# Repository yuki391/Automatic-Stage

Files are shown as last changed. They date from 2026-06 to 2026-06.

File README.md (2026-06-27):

# 自動溶着ステージ

超音波溶着機を動かすための自動溶着ステージを制作したので、共有します。

## ファイルの説明
* **公開版.step**
  CADデータです。
* **自動ステージ用部品.xlsx**
  購入部品と3Dプリンターで製作した部品の一覧です。
* **使い方.pptx**
  私の環境で動かすときのマニュアル資料です。参考までに。
* **回路図.pptx**
  どのような配線をしたのかを記載しています。
* **その他 (.py, .json)**
  プログラムファイル群です。設定ファイル（.json）含め、すべて同じディレクトリで使用してください。
  ※ `foot_button.py`は溶着機をフットペダルでオンオフできるようにするものです。単独で実行するものではなく、`main_app.py`に組み込まれて動作します。

## 免責事項
本プロジェクトは素人が作成したものであり、改善できる点や間違いが含まれている可能性があります。
本データ（プログラム、CAD、回路図等）を使用したことによって生じたいかなる損害、事故、トラブルについても、作者は一切の責任を負いかねます。ご自身の責任において、安全に十分配慮した上でご活用ください。

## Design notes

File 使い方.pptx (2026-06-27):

## 自動ステージの使い方 (How to use an automatic stage)

- 2025/11/27

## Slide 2

目次

・P3 全体の流れ (Overall Flow)
・P4 注意事項 (Precautions)
・P5 手動で溶着する方法 (How to Weld Manually)
・P7 溶着方法 (Welding Method)
・P17 Q＆A

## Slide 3

流れ (flow)

溶着したい形を作製しdxfファイルで読み込ませる
(Create the shape you want to weld and import it as a DXF file.)
↓
溶着点データを作製・修正
(Creating and correcting welding point data)
↓
溶着開始
(Start of welding)

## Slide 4

注意事項 (Precaution)

・何かあったら非常停止ボタンを押してください．押した場合は最初からpythonプログラムの起動からやり直してください
(If anything happens, press the emergency stop button. If pressed, please restart the Python program from the beginning.)
・溶着機の先端や溶着したところは熱い可能性があるので気を付けてください
(Be careful, as the tip of the welding machine and the welded areas may be hot.)
・途中で緊急停止やトラブルがあると、溶着機の先端が下についていることがあります。この状態でXY軸を動かさないでください。
Z軸高さというところがあるのでここのパルス指定を2000にするか、pythonプログラムを終了し、もう一度立ち上げてください
(If an emergency stop or issue occurs mid-operation, the welder tip may remain lowered. Do NOT move the X and Y axes in this state. > Please set the パルス value in the " Z軸高さ" field to 2000, or close the Python program and restart it.)

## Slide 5

０　溶着機の使い方 (How to use)

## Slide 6

0　溶着機の外し方 (Removal of the Welding Machine)

①ねじを外す (Remove the screws)

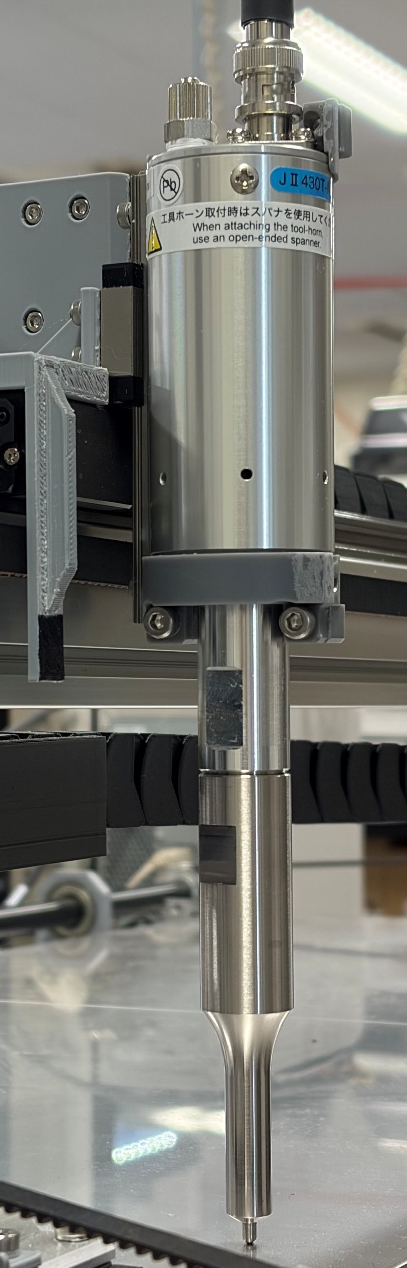
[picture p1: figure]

②ケーブルチェーンから線を外す
(Remove the cables from the cable chain)

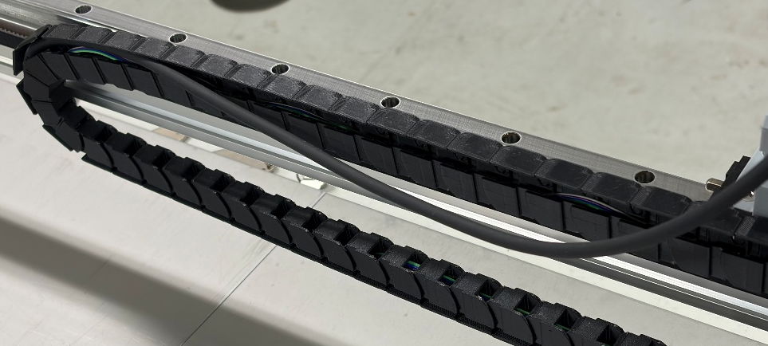
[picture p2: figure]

戻すときは逆の動作で。
溶着機本体を固定するときは向きに注意
(To reassemble, reverse the procedure. Note: Make sure the welding machine is facing the correct direction when securing it)

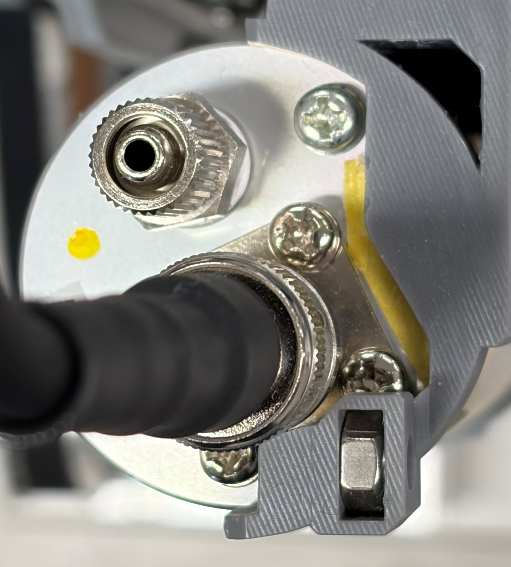
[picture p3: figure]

溶着機を上からみた図
(Top view of the welding machine)

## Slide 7

１　.dxfファイルを作製 (Create the DXF file)

SoildworksかFusion360でdxfファイルとして形をつくる
※注意※
複数の線が重なって構成されてるとエラーが出る
(Overlapping lines will cause an error)

〇

✕

線が重なってる

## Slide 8

２　配線を確認 (Check the wiring)

・コンセントに以下のものが差さっているか
(Check if the following are plugged into the outlet:)
①24V電源
②超音波溶着（本体後ろの電源をONに）
③Dynamixel
・パソコンと入出力ターミナルがつながってるか
(Check if the PC and the I/O terminal are connected)
・非常停止ボタンが押されたままになってないか
(Make sure the emergency stop button is not kept pressed down.)

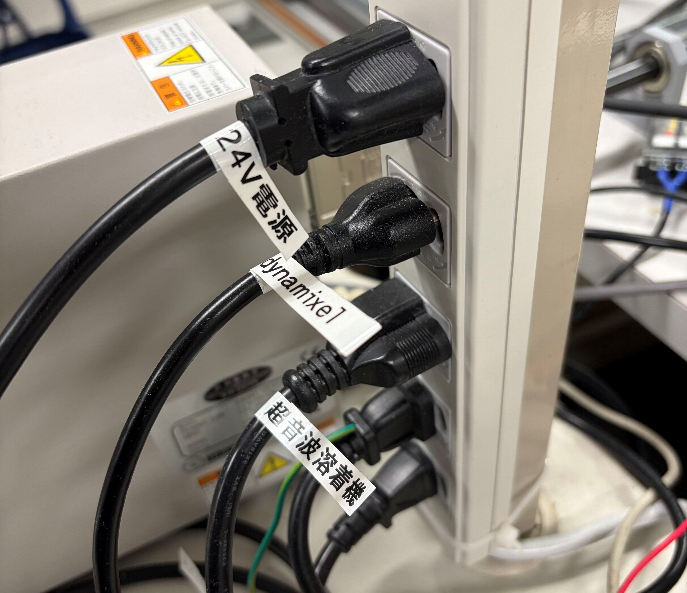
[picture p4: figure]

下二つのプラグはパソコンとモニター

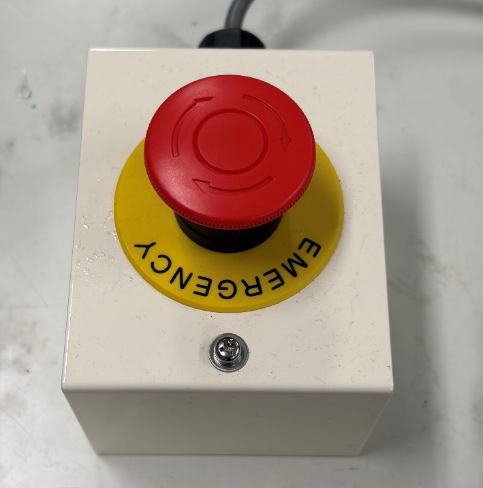
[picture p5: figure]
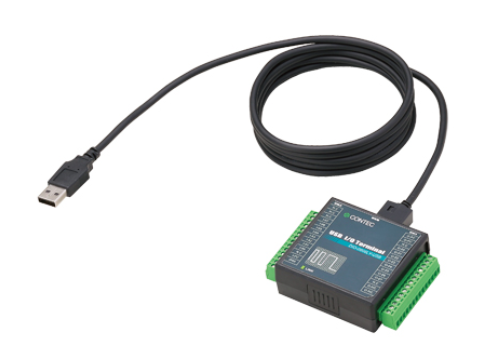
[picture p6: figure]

入出力ターミナル

押すとオン，赤いところを回すとオフ

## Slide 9

２　溶着用プログラムを起動 (Launch the welding program)

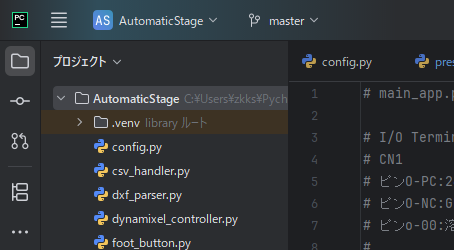
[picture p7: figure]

Pycharmを起動しAutomaticStageというプロジェクトを開く
(Launch PyCharm and open the "AutomaticStage" project)

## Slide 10

２　溶着用プログラムを起動 (Launch the welding program)

main_appを実行
(Run main_app)

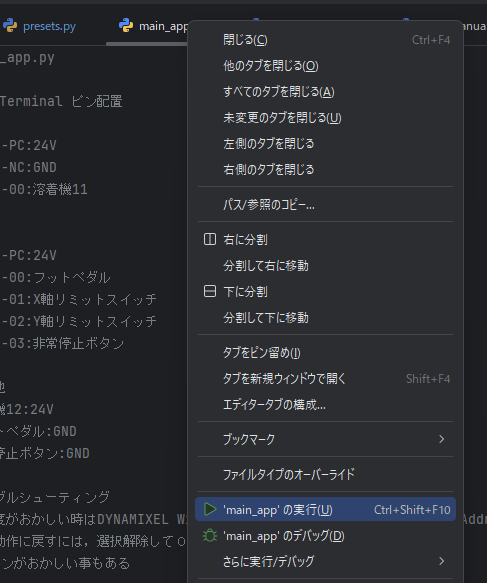
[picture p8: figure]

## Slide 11

３　手動操作画面

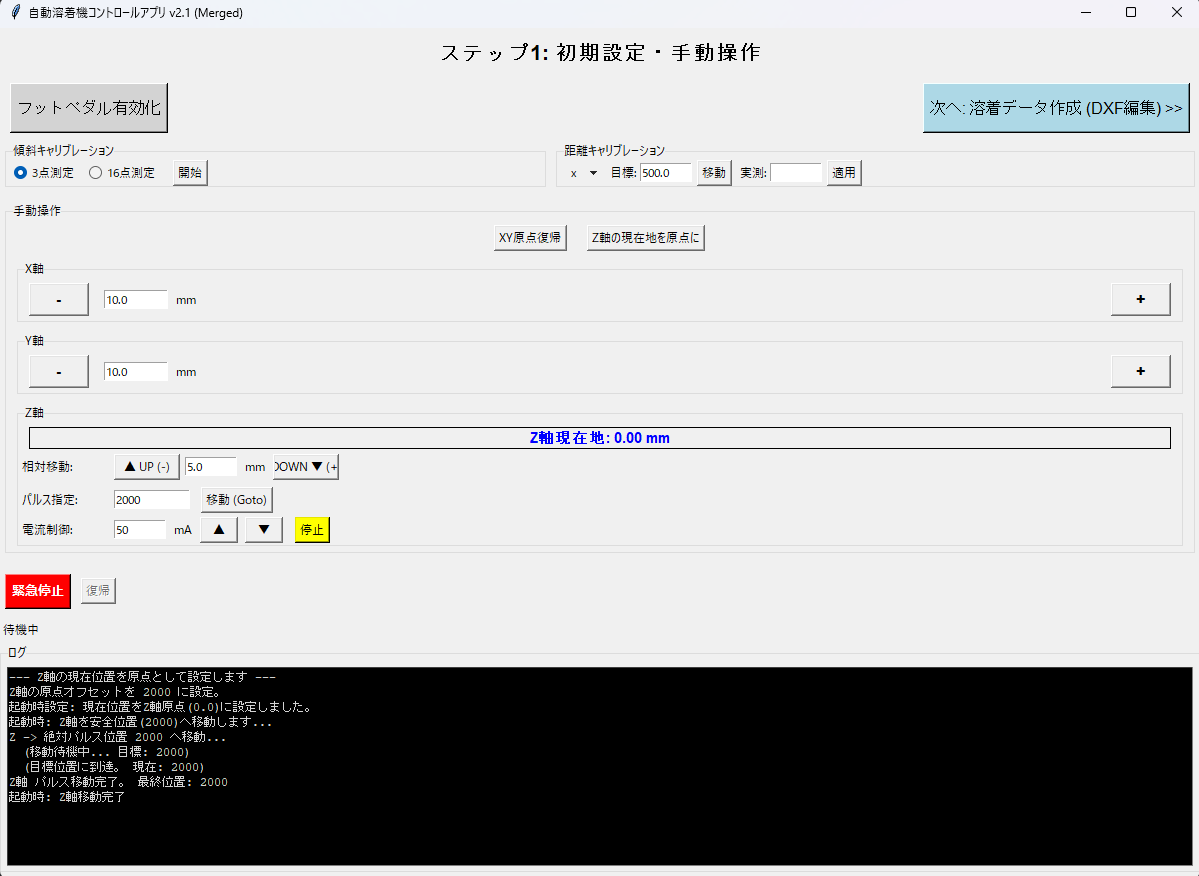
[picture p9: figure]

フットペダルで超音波溶着をオンオフできる
溶着機を手で持って手動で溶着するときのみ使う
Ultrasonic welding can be turned on and off using the foot pedal. Use this only when performing manual welding while holding the welder by hand.

手動で自動ステージを操作できる画面．
何もしなくていいので
次に進む
This screen allows you to operate the automatic stage manually. No action is required; proceed to the next step.

未実装

モニターの回転数と実際に
動く距離を合わせる（P14?）

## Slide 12

４　データの読み込み (Import Data)

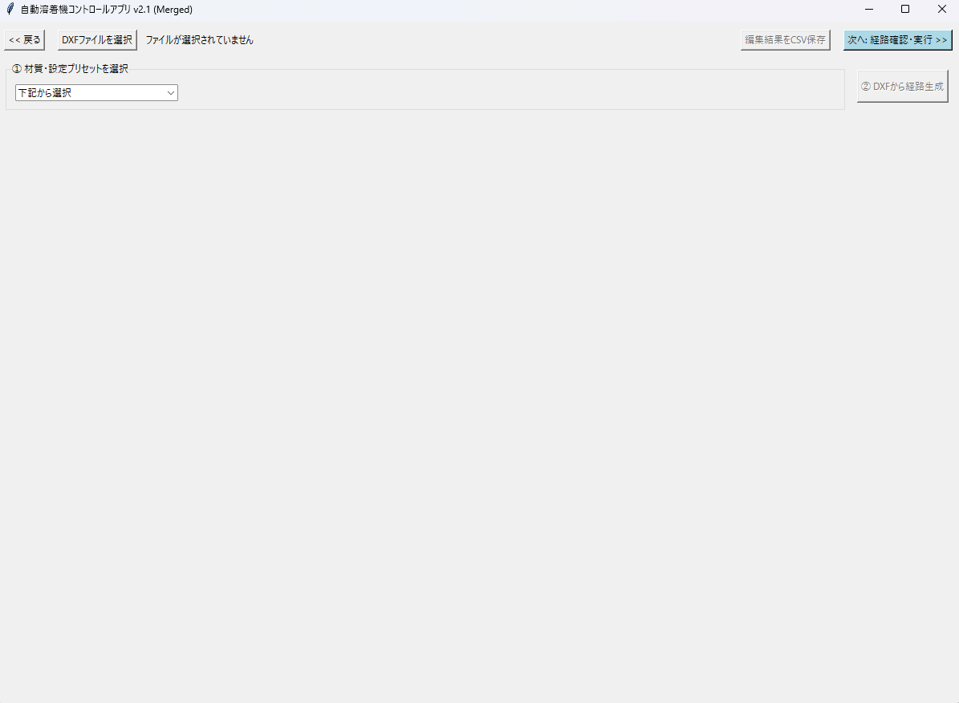
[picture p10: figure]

①作りたいdxfファイルを選択
Select the DXF file you want to create.

②溶着条件を選ぶ
preset.pyで変更可能．
〈パラメーター〉
溶着点の間隔、溶着時の押し付け力、
溶着時間（溶着機本体でも設定できる）、（溶着パワーは溶着機本体で変更）．．．
Select the welding conditions . These can be modified in preset.py. Welding point interval (pitch)Welding contact force (pressing force)Welding time (can also be configured on the welder itself)(Note: Welding power must be changed directly on the welder)

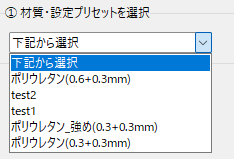
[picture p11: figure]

③ここをクリックする
Click here

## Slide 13

５　溶着点の確認・編集 (Confirm and Edit Welding Points)

赤い丸で溶着点が表示される
(The welding points are displayed as red circles)

〈溶着点を自分でつけたい場合 (If you want to add welding points manually) 〉
移動、拡大縮小のボタンをオンにして位置を調整.
マウスの右クリックで
溶着点の追加や削除
（最後に追加された点は一番最後に溶着される）
(Turn ON the Move or Scale buttons to adjust the position.Right-click with the mouse to add or delete welding points.Note: The last point added will be the last one to be welded)

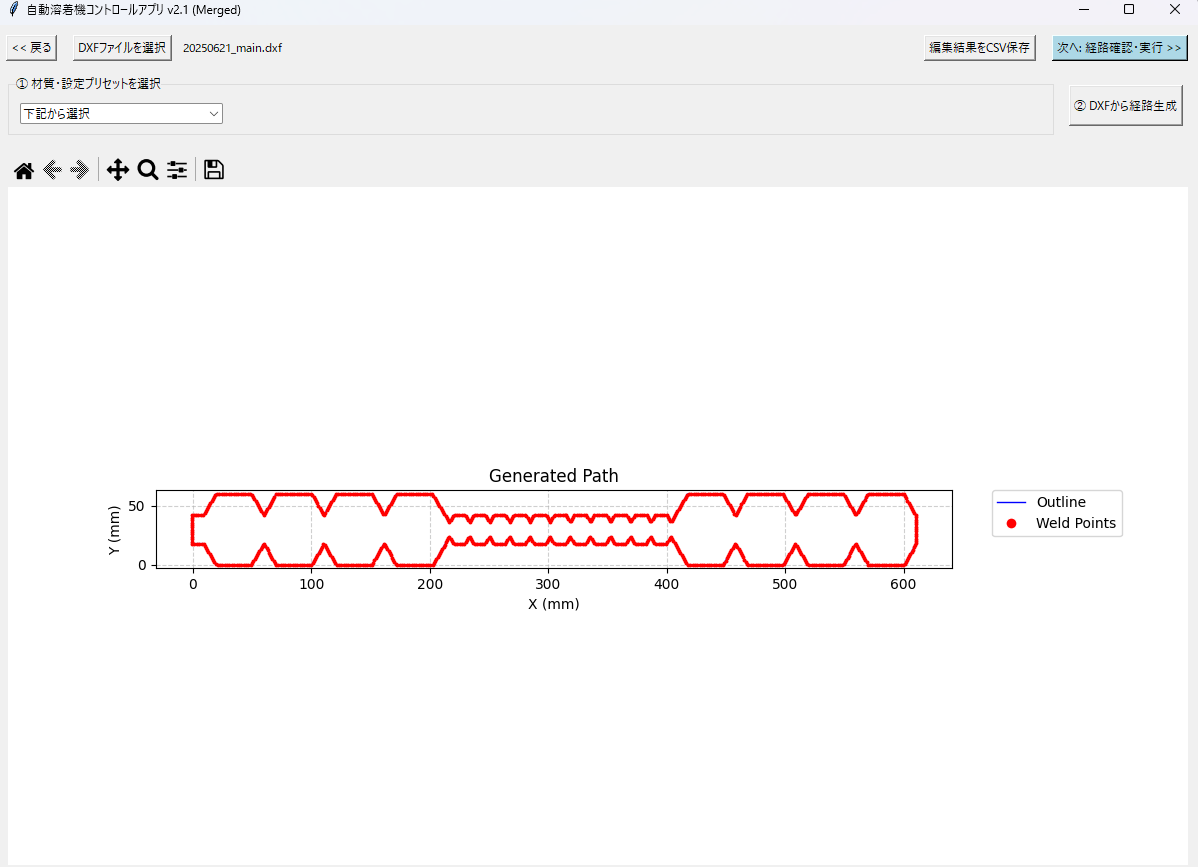
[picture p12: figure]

最後にここを押す
(Click Here for Next Page)

移動

拡大縮小

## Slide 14

６　溶着実行 (Execute Welding)

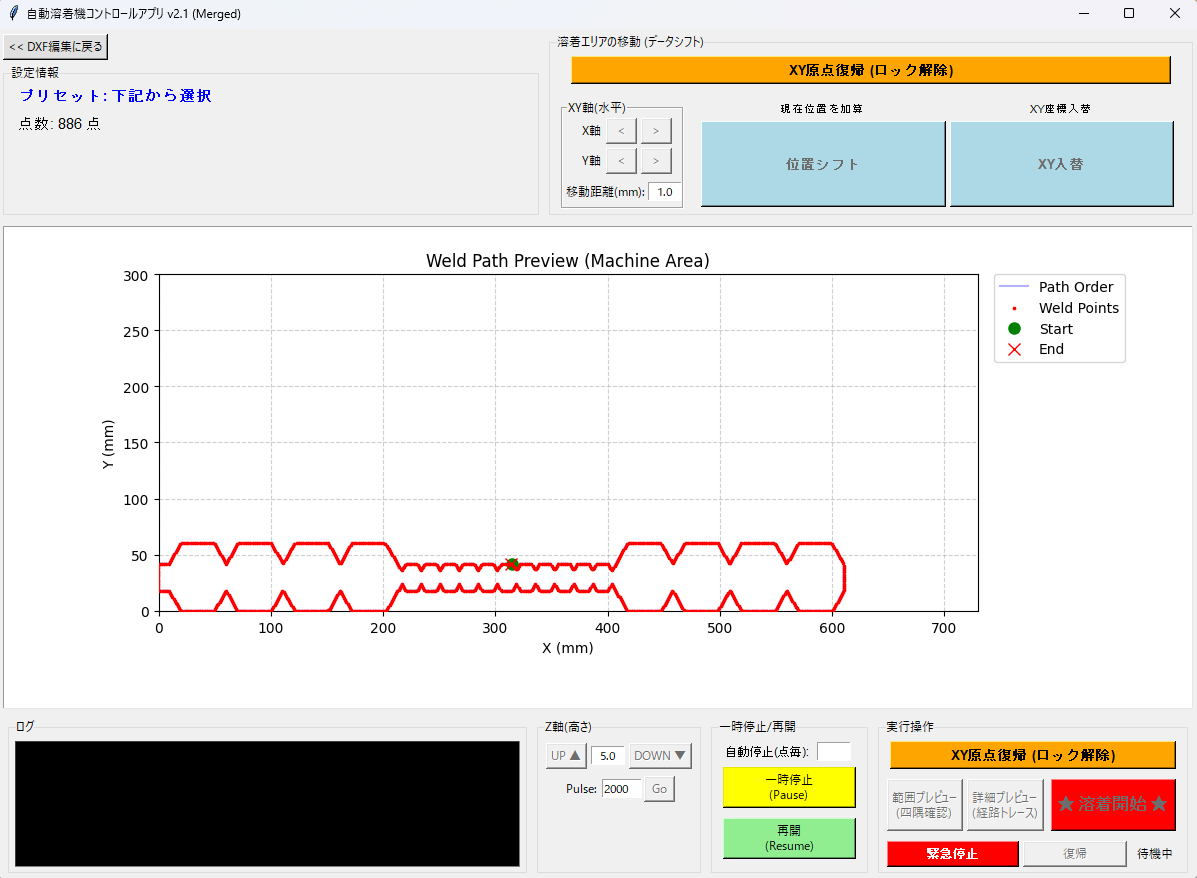
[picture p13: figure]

②溶着位置の変更
ここを押すとXY軸が動く。ワンクリックの移動距離も指定可能
その状態で位置シフトというものを押せばその位置が原点になり，溶着位置を変更できる
(Changing the Welding PositionPressing here moves the X and Y axes. You can also specify the travel distance per click.By pressing "Position Shift" in that state, that current position becomes the new origin, allowing you to change the welding position.)

①最初にここを押す.
XY軸が原点に戻る
(Press here first.The X and Y axes will return to their origins.)

溶着点の総数
(Total Number of Welding Points)

XY画面に表示されている溶着点を回転できる
(Allows you to rotate the welding points displayed on the screen.)

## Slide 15

６　溶着実行 (Execute Welding)

③溶着したい素材をセットし、磁石で端を止める。溶着機と干渉しないように注
(Set the material to be welded and secure the edges with magnets. Be careful not to place the magnets inside the welding area.)

④プレビューを押すと右上右下左上左下の４点で溶着範囲を確認できる．隣の詳細プレビューはすべての溶着点に沿って溶着機が動くが時間がかかる
(Pressing “範囲レビュー” allows you to check the welding area using four points: top-right, bottom-right, top-left, and bottom-left. The adjacent “詳細プレビュー" moves the welder along all welding points, but it takes more time.)

溶着機は長時間使用していると発熱する．ここに数字を入れると，溶着数がその数になると一時停止する．復帰は下の「再開」から
300点に1回は必要かも
(The welder generates heat during prolonged use. Entering a number here will pause the operation once the number of welds reaches that count. You can resume by clicking the "Resume" button below.(Recommendation: A pause may be necessary once every 300 points.))

⑤最後にここを押して開始
(Finally, press here to start welding.)

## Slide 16

Q＆A

・モーターが動かない，反応しない (The motor does not move or respond)
→電源がつながってない，
非常停止ボタンが押されてる，
モーターがオーバートルクとなっている．この場合はR＋managerでモーターを初期化
(The power might not be connected,
the emergency stop button may be pressed,
or the motor may be in an over-torque condition. In this case, please initialize the motor using R+ Manager.)
・気になることがあれば，githubのリンクをgeminiの「コードをインポート」にいれれば色々教えてくれる

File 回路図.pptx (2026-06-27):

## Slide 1

GND

AC
アダプター

非常停止
ボタン(NC)

溶着機

AC
100V

非常停止
ボタン(NO)

24V

12

11

入出力ターミナル

Y軸
モーター

SMPS2

O-PC

24V

X軸
モーター

U2D2

O-00

I-03

Z軸
モーター

PC

I-02

青ケーブル

GND

Y軸
リミットスイッチ

I-01

I-00

茶ケーブル

24V

白ケーブル

I-PC

GND

青ケーブル

X軸
リミットスイッチ

白ケーブル

フットスイッチ
（足踏みペダルで溶着機を操作したい場合）

O-NC

GND

茶ケーブル

24V

GND

24V

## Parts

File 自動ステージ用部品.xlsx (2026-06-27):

購入品
品名 | 型番 | メーカー | URL | 備考 | 個数 | 単価 | 価格(目安)
アルミフレーム ５シリーズ Nタイプ 正方形 ２０×２０ｍｍ １列溝 ４面溝 | NFS5-2020-786 | ミスミ | https://jp.misumi-ec.com/vona2/detail/110311092599/ |  | 2 | 396 | ¥792
アルミフレーム ５シリーズ Nタイプ 正方形 ２０×２０ｍｍ １列溝 ４面溝 | NFS5-2020-360 | ミスミ | https://jp.misumi-ec.com/vona2/detail/110311092599/ |  | 2 | 176 | ¥352
アルミフレーム ５シリーズ Nタイプ 長方形 ２０×４０ｍｍ ２列溝 ４面溝 | NFS5-2040-927 | ミスミ | https://jp.misumi-ec.com/vona2/detail/110311092869/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 |  | 1 | 902 | ¥902
アルミフレーム ５シリーズ Nタイプ 長方形 ２０×４０ｍｍ ２列溝 ４面溝 | NFS5-2040-100 | ミスミ | https://jp.misumi-ec.com/vona2/detail/110311092869/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 |  | 2 | 282 | ¥564
アルミフレーム ５シリーズ Nタイプ 長方形 ２０×６０ｍｍ ２０×８０ｍｍ ３列溝以上 ４面溝 | NFS5-2060-480 | ミスミ | https://jp.misumi-ec.com/vona2/detail/110311093859/ |  | 2 | 616 | ¥1232
５シリーズ（溝幅６ｍｍ）用 アルミフレーム用後入れナット【1～100個入り】 | HNTF5-4 | ミスミ | https://jp.misumi-ec.com/vona2/detail/110300461850/?searchFlow=results2products&searchCategorySpec=00 | このナットはバネナットより小型（短い）なので、ボルトの間隔を短くできます | 30 | 48 | ¥1440
５シリーズ（溝幅６ｍｍ）用 アルミフレーム用後入れバネナット【1～100個入り】 | PACK-HNTP5-4 | ミスミ | https://jp.misumi-ec.com/vona2/detail/110302608410/ | アルミフレームに後入れ出来、重力で動かないので便利です | 1 | 4676 | ¥4676
５シリーズ（溝幅６ｍｍ） －１列溝用－ 突起付反転ブラケット | HBLFSNF5 | ミスミ | https://jp.misumi-ec.com/vona2/detail/110300437260/ |  | 16 | 77 | ¥1232
５シリーズ（溝幅６ｍｍ）用薄型ブラケット | HBLSS5 | ミスミ | https://jp.misumi-ec.com/vona2/detail/110300438930/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 |  | 4 | 73 | ¥292
【オーダー】ブラケットフレーム AFLH-4040 | AFLH-4040-33 | モノタロウ | https://www.monotaro.com/g/02364574/ | 長さ：33 mm 買いましたが３Dプリンターでつくってもよかったです | 4 | 152 | ¥608
 |  |  |  |  |  |  | ¥0
SS400フリープレート(WEB掲載品) | SS400-6F-LSB-NNN-800-400-10-CAR | ミスミ | https://jp.misumi-ec.com/vona2/detail/110310109439/?searchFlow=results2products&searchCategorySpec=00 | 土台用です。溶着したい素材を磁石で固定するため、鉄を選びました | 1 | 23957 | ¥23957
錆止めスプレー | 45522346 | モノタロウ | https://www.monotaro.com/p/4552/2346/?t.q=%8EK%8E~%82%DF | 土台のさび止めです | 1 | 571 | ¥571
カッターマット 再生PVC製 5層タイプ グレー色 | 61730979 | モノタロウ | https://www.monotaro.com/p/6173/0979/?t.attr_f388=A1&t.pt=3000 | サイズ：A1 【重要→】当初、溶着に加え全自動カットも導入する予定だったので、土台はカッターマットを一番上に敷き、その下に安く変形しなく磁石につく鉄板を置くことを考えていました。超音波溶着は表面が金属の土台の上でやるほうがいいので、自動でカットしないかたは錆びない金属を一番上に敷くといいでしょう。私はカットはあきらめたので、一つ下の項目にあるステンレス板を追加で買い土台の一番上に敷いていました | 1 | 2528 | ¥2528
【オーダー】SUS304切板 2Bシャーリング切断 厚さ2mm | 注文コード 32589934 品番 - | ノーブランド | https://www.monotaro.com/p/3258/9934/ | 400mm×400mm | 2 | 8798 | ¥17596
 |  |  |  |  |  |  | ¥0
標準ベルト S3M | 100S3M1035G | 三ツ星ベルト | https://jp.misumi-ec.com/vona2/detail/221000014921/ |  | 2 | 1398 | ¥2796
標準ベルト S3M | 100S3M2100G | 三ツ星ベルト | https://jp.misumi-ec.com/vona2/detail/221000014921/ |  | 1 | 2800 | ¥2800
【エコノミーシリーズ】 RoHS対応 タイミングプーリ S3M 固定寸法タイプ | C-HTPA30S3M100-A-P15 | ミスミ | https://jp.misumi-ec.com/vona2/detail/110310313739/ |  | 3 | 1012 | ¥3036
【エコノミーシリーズ】 RoHS対応 アイドラー S3Mタイプ | C-AHTF30S3M100 | ミスミ | https://jp.misumi-ec.com/vona2/detail/110310405719/?PNSearch=C-AHTF30S3M100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 |  | 4 | 1925 | ¥7700
【エコノミーシリーズ】 RoHS対応 アイドラー 背面テンションタイプ | C-AFDF15-30 | ミスミ | https://jp.misumi-ec.com/vona2/detail/110310461429/?CategorySpec=SP100255136%3A%3Ae |  | 2 | 1177 | ¥2354
 |  |  |  |  |  |  | ¥0
回転軸 廻り止めタイプ | SFRV15-937-F30-T20-W14 | ミスミ | https://jp.misumi-ec.com/vona2/detail/110300087170/?list=PageCategory&clkid=clkid_basic_shape_template |  | 1 | 4741 | ¥4741
【エコノミーシリーズ】深溝玉軸受 両シールド形 軽荷重タイプ | C-B6002ZZ | ミスミ | https://jp.misumi-ec.com/vona2/detail/110302590550/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 |  | 4 | 128 | ¥512
高精度ディスクカップリング 高トルク・セットスクリュータイプ | CPKNSLK31.8-15-15 | ミスミ | https://jp.misumi-ec.com/vona2/detail/110310309959/?HissuCode=CPKNSLK31.8-15-15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 |  | 1 | 2618 | ¥2618
【エコノミーシリーズ】 RoHS対応 重荷重用リニアガイド | C-SX2R24-460 | ミスミ | https://jp.misumi-ec.com/vona2/detail/110302734840/?bid=bid_STC_LP2401_oth4_sc3141_20209 |  | 2 | 9526 | ¥19052
【エコノミーシリーズ】 RoHS対応 重荷重用リニアガイド | C-SX2R24-880 | ミスミ | https://jp.misumi-ec.com/vona2/detail/110302734840/?bid=bid_STC_LP2401_oth2_sc3141_20209 |  | 1 | 12254 | ¥12254
ミニチュアリニアガイド 標準ブロック | SSEBZ10-95 | ミスミ | https://jp.misumi-ec.com/vona2/detail/110302586530/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 |  | 1 | 2613 | ¥2613
 |  |  |  |  |  |  | ¥0
絶縁型デジタル入出力ターミナル | 注文コード11692704 品番DIO-0808LY-USB | CONTEC(コンテック) | https://www.monotaro.com/p/1169/2704/?t.q=DIO-0808LY-USB | 入出力ターミナル。溶着機に信号を送ったり、リミットセンサーを読み取ります | 1 | 39578 | ¥39578
 |  |  |  |  |  |  | ¥0
ネオジムキャップマグネット | 注文コード 04425596 品番 MNCP0002 | マグテック | https://www.monotaro.com/p/0442/5596/ | 高さがないので溶着機と干渉しにくく便利ですが、もう少し強力なものでもいいかもしれません。 | 6 | 296 | ¥1776
 |  |  |  |  |  |  | ¥0
マイクロフォトセンサ 溝形小型タイプ ケーブル式 | C-MSX672N-2M | ミスミ | https://jp.misumi-ec.com/vona2/detail/110310550529/ | 形状 T型 | 1 | 847 | ¥847
マイクロフォトセンサ 溝形小型タイプ ケーブル式 | C-MSX674N-2M | ミスミ | https://jp.misumi-ec.com/vona2/detail/110310550529/ | 形状 Y型 | 1 | 880 | ¥880
 |  |  |  |  |  |  | ¥0
DYNAMIXEL XM430-W210-R | 品番 902-0119-000 | ROBOTIS | https://e-shop.robotis.co.jp/product.php?id=45 | モーターです | 3 | 31504 | ¥94512
ACアダプター 12V 7A (84W) Φ2.5 |  | ROBOTIS | https://e-shop.robotis.co.jp/product.php?id=331 | 以下5つはモーターを動かすのに必要なものです。間違っている可能性もあるので念のため調べてください | 1 | 5918 | ¥5918
SMPS2Dynamixel |  | ROBOTIS | https://e-shop.robotis.co.jp/product.php?id=175 |  | 1 | 1122 | ¥1122
USBシリアル変換インターフェース U2D2 |  | ROBOTIS | https://e-shop.robotis.co.jp/product.php?id=190 |  | 1 | 6963 | ¥6963
Robot Cable-X4P(JST-JST) 10pcs |  | ROBOTIS | https://e-shop.robotis.co.jp/product.php?id=217 | モーターに付属しているかもしれません。 | 1 | 1683 | ¥1683
Robot Cable-X4P(Convertible) 10pcs |  | ROBOTIS | https://e-shop.robotis.co.jp/product.php?id=433 | モーターに付属してないので買う必要があります | 1 | 1936 | ¥1936
 |  |  |  |  |  |  | ¥0
瞬時 フットスイッチ フットスイッチ 瞬時電力 フットペダルスイッチ スリップ防止設計、【定格電圧6V-24-36-220-380V】家庭用ミシン工作に適しています（線の長さ15cm ）2枚入 | B0D7PTGY23 | LEACAGR | https://amzn.asia/d/fQzRnqV | 足で溶着機を操作するためです。手動で溶着するときに便利です。 | 1 | 1180 | ¥1180
非常停止ボタン |  |  |  | １２V～モーターの間に設置するといいでしょう。相場の価格を仮で入れています | 1 | 2000 | ¥2000
 |  |  |  |  |  |  | ¥0
小型超音波溶着機 | JⅡ431SA-外部I0なし | 精電舎電子工業株式会社 | https://www.sedeco.co.jp/ |  | 1 | 678700 | ¥678700
小型超音波溶着機の先端 |  | 精電舎電子工業株式会社 |  | 先端が小さい丸のものを買いました。値段はおおよその値です | 1 | 100000 | ¥100000
 |  |  |  |  |  |  | ¥0
 |  |  |  |  |  | 合計 | ¥1054313
3Dプリント（CADデータを参照してください）
溶着機固定
タイミングベルト固定 | 2
軸受_ベアリングの型番C-B6002ZZ | 4個程度 | ベアリングを本体に固定する用
アイドラー固定＿右
dynamixel-カップリング＿X軸アダプター
dynamixel-カップリング＿Y軸アダプター
アイドラー固定＿左
アイドラー固定＿左右共通 | 2
Y軸モータ受け
Y軸アイドラー上固定＿右
X軸モータ受け
Y軸アイドラー＿張力用
ラック
Y軸センサーアダプター |  | 部品２個あります
Z軸モーター受け
X軸センサーアダプター
ピニオン
ケーブルチェーン終わり
ケーブルチェーン始まり
ケーブルチェーン支持用
ケーブルチェーンver2片側 | たくさん | PLAではなくPETGなどの靭性に優れた素材を使うと取り付けの際に壊しにくいです

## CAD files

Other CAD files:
test_50mm v1.dxf

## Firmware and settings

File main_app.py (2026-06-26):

# main_app.py

# I/O Terminal ピン配置
# CN1
# ピンO-PC:24V
# ピンO-NC:GND
# ピンo-00:溶着機11
#
# CN2
# ピンI-PC:24V
# ピンI-00:フットペダル
# ピンI-01:X軸リミットスイッチ
# ピンI-02:Y軸リミットスイッチ
# ピンI-03:非常停止ボタン
#
# その他
# 溶着機12:24V
# フットペダル:GND
# 非常停止ボタン:GND

# トラブルシューティング
# 加速度がおかしい時はDYNAMIXEL Wizard 2.0 等でモーターの Drive Mode (Address 10) を確認し、Time-based Profileになっていないか確認。
# 通常動作に戻すには，選択解除して０にする。
# Pゲインがおかしい事もある



# main_app.py

import tkinter as tk
from tkinter import messagebox
import sys

# 各ページクラスのインポート
from page_manual_control import PageManualControl
from page_dxf_editor import PageDxfEditor
# 統合されたページをインポート
from page_merged import PageMergedPreviewExecution

# ハードウェア関連
from myADconvert import ADfunc
from motion_system import MotionSystem
from io_controller import WelderController, SensorController
import config
import presets


class MainApp(tk.Tk):
    def __init__(self):
        super().__init__()
        self.title("自動溶着機コントロールアプリ v2.1 (Merged)")
        self.geometry("1200x850")

        # --- データ共有用 ---
        default_preset = list(presets.WELDING_PRESETS.keys())[0]
        self.shared_data = {
            "weld_points": [],
            "preset_name": default_preset
        }

        # --- ハードウェア初期化 ---
        self.hardware = {
            "dio": None, "motion": None, "welder": None, "sensors": {}, "emergency_sensor": None
        }
        self._init_hardware()

        # --- 画面コンテナ ---
        container = tk.Frame(self)
        container.pack(side="top", fill="both", expand=True)
        container.grid_rowconfigure(0, weight=1)
        container.grid_columnconfigure(0, weight=1)

        self.pages = {}
        # ページリストを変更（統合ページを使用）
        page_classes = (PageManualControl, PageDxfEditor, PageMergedPreviewExecution)

        for PageClass in page_classes:
            page_name = PageClass.__name__
            frame = PageClass(parent=container, controller=self)
            self.pages[page_name] = frame
            frame.grid(row=0, column=0, sticky="nsew")

        self.show_page("PageManualControl")

    def _init_hardware(self):
        print("ハードウェアを初期化しています...")
        try:
            dio = ADfunc('DIO')
            if not dio.init("DIO000"):
                messagebox.showerror("エラー", "CONTEC DIOの初期化に失敗しました。")
                return
            self.hardware["dio"] = dio
            self.hardware["motion"] = MotionSystem(log_callback=print)
            self.hardware["welder"] = WelderController(dio)
            self.hardware["sensors"] = {
                'x': SensorController(dio, config.LIMIT_SWITCH_X_PIN),
                'y': SensorController(dio, config.LIMIT_SWITCH_Y_PIN)
            }
            self.hardware["emergency_sensor"] = SensorController(dio, config.EMERGENCY_STOP_PIN)
            print("ハードウェア初期化完了")
        except Exception as e:
            messagebox.showerror("初期化エラー", f"ハードウェア初期化中にエラーが発生しました:\n{e}")

    def show_page(self, page_name):
        if page_name not in self.pages:
            return
        frame = self.pages[page_name]
        frame.tkraise()
        if hasattr(frame, 'on_page_show'):
            frame.on_page_show()

if __name__ == "__main__":
    app = MainApp()
    app.mainloop()
